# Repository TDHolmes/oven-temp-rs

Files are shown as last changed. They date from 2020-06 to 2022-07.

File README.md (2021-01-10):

# Oven Temperature Monitor

This project utilizes a [Feather M0] board, a [quad alphanumeric display], and a
[thermocouple amplifier] to monitor the temperature of dumb ovens that do
not have digital temperature readout. It is battery opperated, and written
in [rust].

Read more about it [on my website!](https://www.holmesengineering.com/oven-temp-rs/)

# Building and Flashing

As this project uses a [Feather M0] board, it has the [HF2 bootloader] pre-installed from
Adafruit. With the [cargo-hf2] crate installed, building and flashing is as simple as:

1. Place board into bootloader mode (double-press the reset button)
2. Run `cargo hf2 <options>`

To install [cargo-hf2], run `cargo install cargo-hf2`. Additional setup may be needed depending
on your OS. Refer to the crates.io page for more information.

# License

This code is licensed under either of:

- Apache License, Version 2.0 ([LICENSE-APACHE](LICENSE-APACHE) or
  http://www.apache.org/licenses/LICENSE-2.0)
- MIT license ([LICENSE-MIT](LICENSE-MIT) or http://opensource.org/licenses/MIT)

at your option.

## Contribution

Unless you explicitly state otherwise, any contribution intentionally submitted for inclusion in the
work by you, as defined in the Apache-2.0 license, shall be dual licensed as above, without any
additional terms or conditions.

# Schematic / Pictures

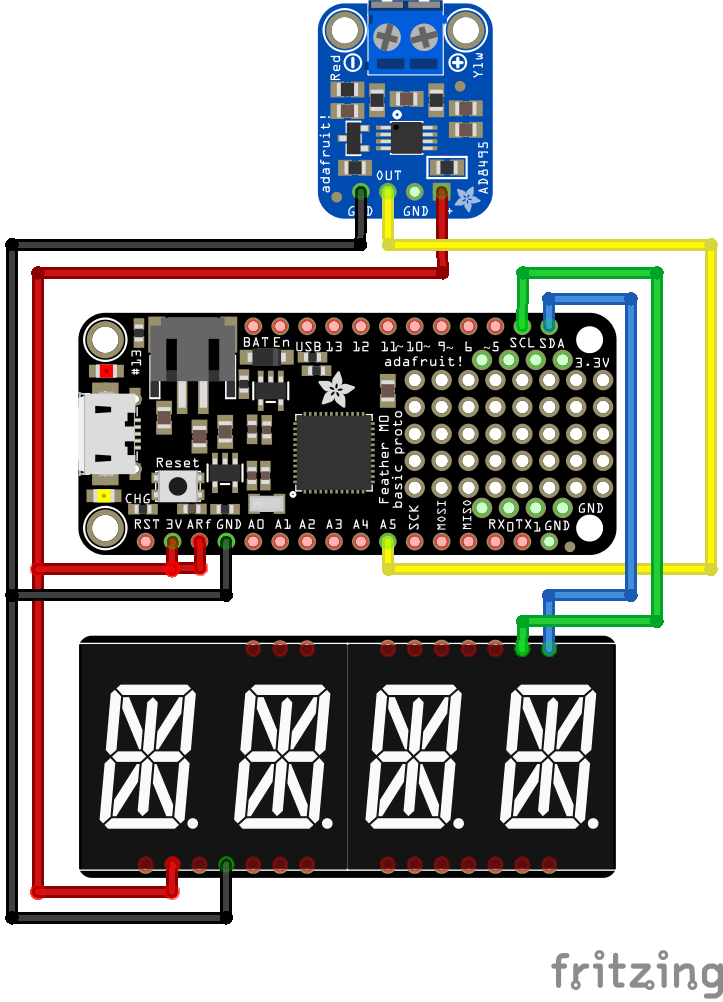
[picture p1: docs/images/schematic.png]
Schematic - very simple


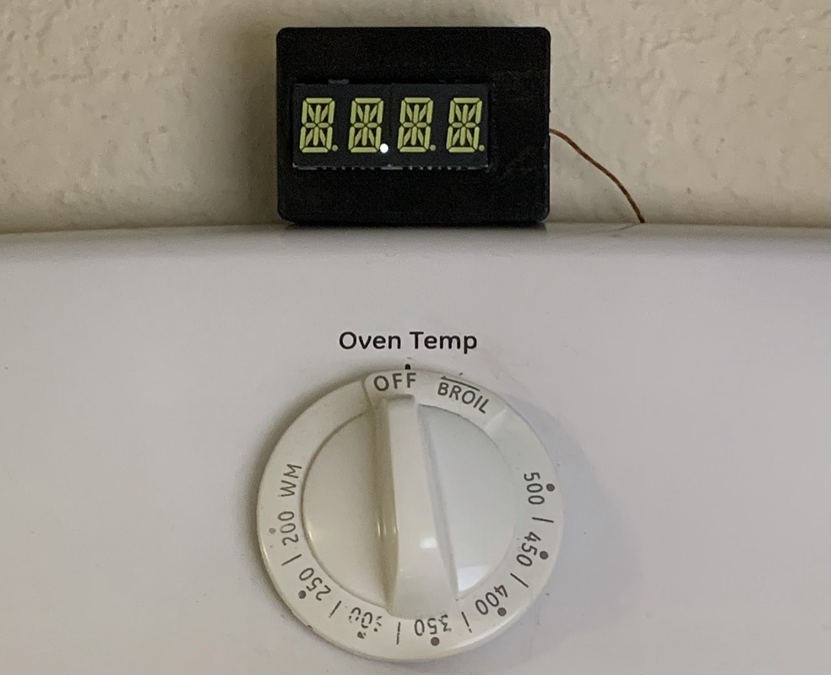
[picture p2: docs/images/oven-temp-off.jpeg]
Picture of the board


[Feather M0]: https://www.adafruit.com/product/2772
[quad alphanumeric display]: https://www.adafruit.com/product/3127
[thermocouple amplifier]: https://www.adafruit.com/product/1778
[rust]: https://rust-lang.org
[oven-temp-board]: https://github.com/TDHolmes/oven-temp-rs/raw/main/docs/images/oven-temp-off.jpeg
[schematic]: https://github.com/TDHolmes/oven-temp-rs/raw/main/docs/images/schematic.png
[HF2 bootloader]: https://github.com/jacobrosenthal/hf2-rs/tree/master/hf2
[cargo-hf2]: https://crates.io/crates/cargo-hf2

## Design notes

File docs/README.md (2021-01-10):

# Rust Oven Temperature Monitor

This project came about when my wife noticed that the oven in our appartment didn't seem to
be at the correct temperature, as everything would bake too quickly. Seeing this as a great
excuse to do a project, I set off on making an oven temperature monitor. To give myself some
constraints, however, I wanted it to be battery powered and last a long time.

My first attempt was written in C using an STM32. you can read more about that [here](https://github.com/TDHolmes/OvenTemp).
This is the new and improved version, written in Rust.



## Hardware Summary

This project utilizes a [Feather M0] board, a [quad alphanumeric display], and a
[thermocouple amplifier] to monitor the temperature of dumb ovens that do
not have digital temperature readout. It is battery opperated, and written
in [rust].

## Initial Implementation

My first cut at this was simple: port all of the basic functionality over from the C-based
version of the project to rust. This was relatively easy given how far along the embedded
rust ecosystem is, especially for these simple projects. Since I'm using a feather M0 board, I used the
wonderful [atsamd-rs] HAL crates. This is a great and welcoming codebase tha also had all of the basic
features I needed to get this project functional. I also took the oportunity to write my own driver for
my alphanumeric display, which I based off of the Adafruit C++ library, with some tweaks for power
I'll get into later on.

## Power Optimizations

I had a functional project up and running quickly, but it definitely wasn't going to work as the
final project. The timer APIs as existed at the time had no capability for interrupt-based
operation, so sleeping the core for power savings wasn't easy. Because of this limitation, I
[opened a PR](https://github.com/atsamd-rs/atsamd/pull/205) for this functionality,
saving 6 mA of current consumption, and I didn't have to worry about interrupt memory saftey since rust didn't
allow me to (easily) do anything unsafe.

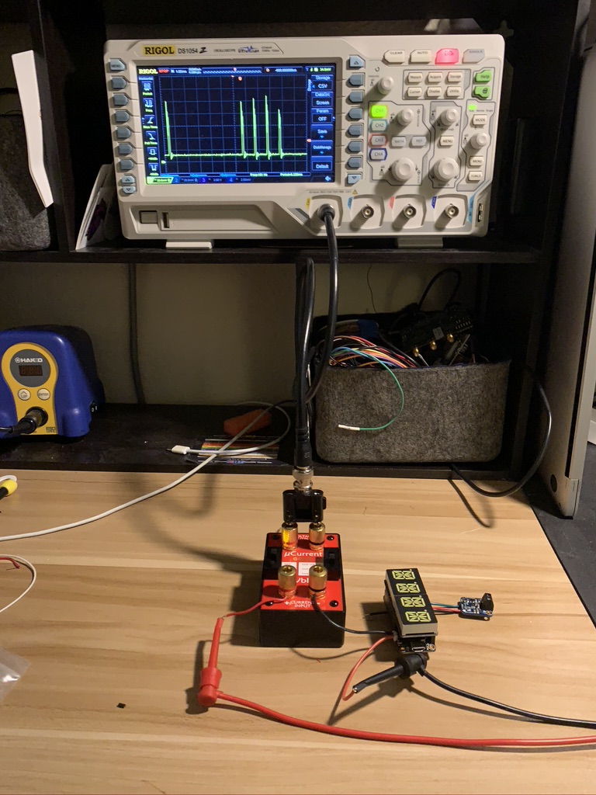
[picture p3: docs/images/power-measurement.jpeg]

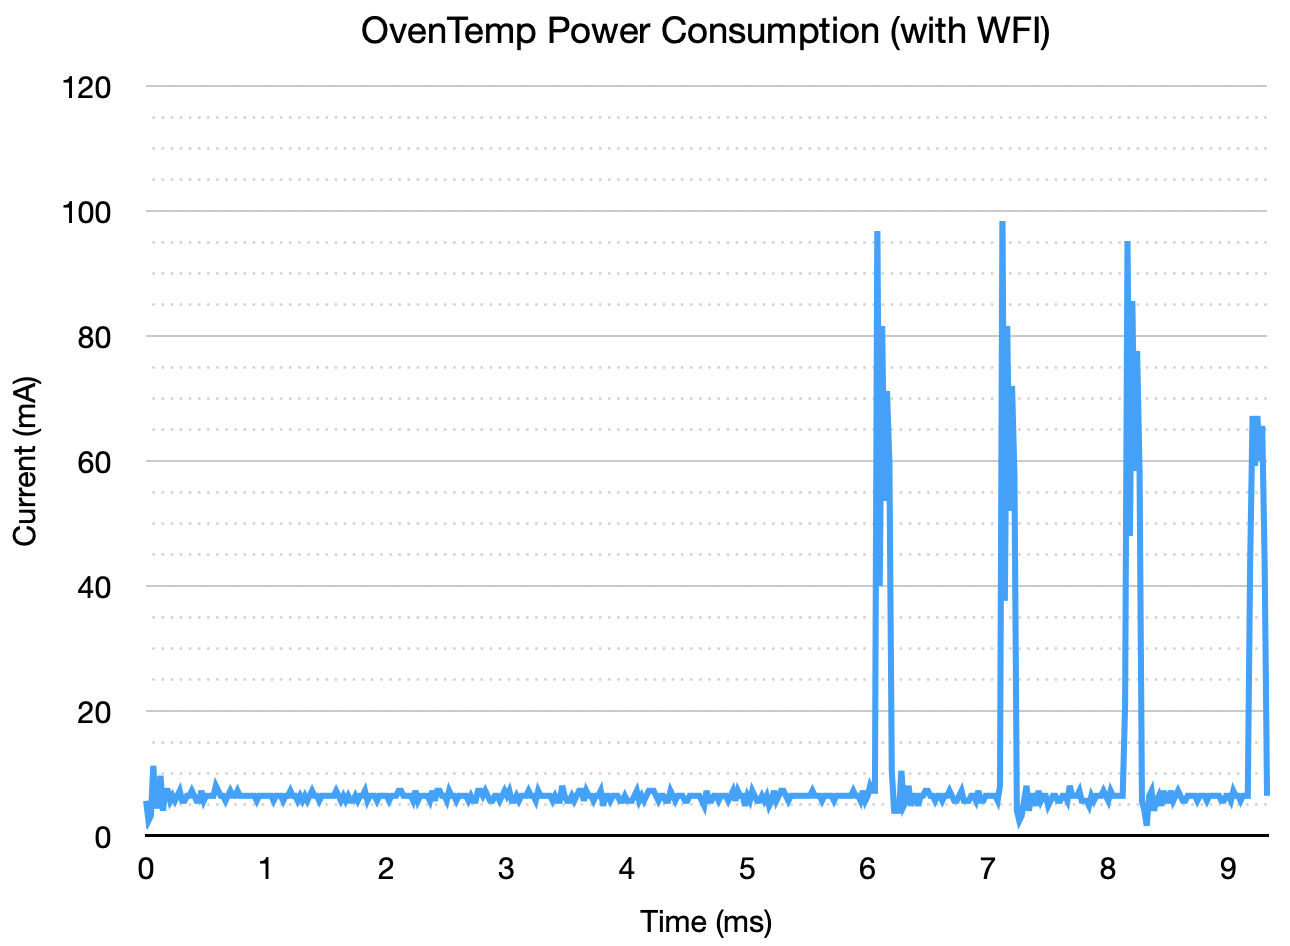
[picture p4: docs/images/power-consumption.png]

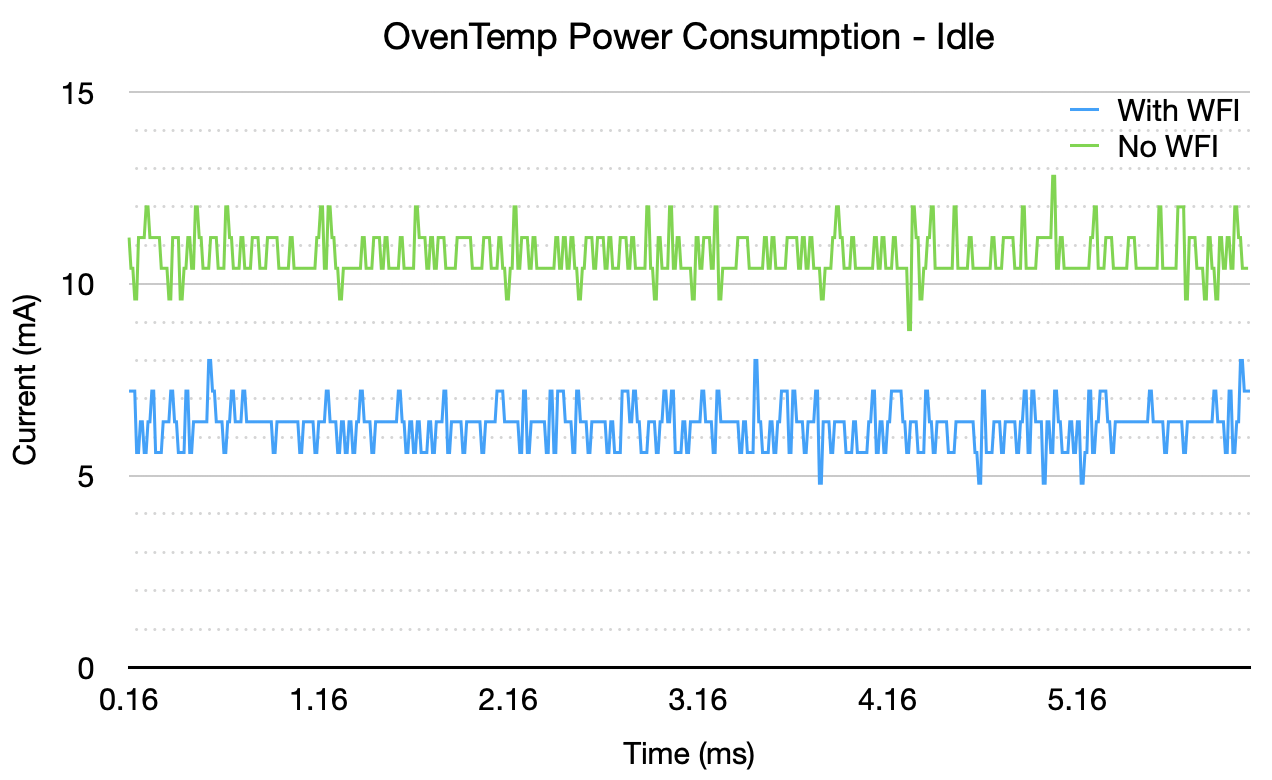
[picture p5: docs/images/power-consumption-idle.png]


This change allowed simple sleeping of the core without powering down much else. A lot more could be
gained by configuring the power management peripheral to sleep more of the cores busses. I implemented
these changes in [this PR](https://github.com/atsamd-rs/atsamd/pull/291), which reduced our current consumption
(apart from the display) from ~870 uA to ~250 uA.

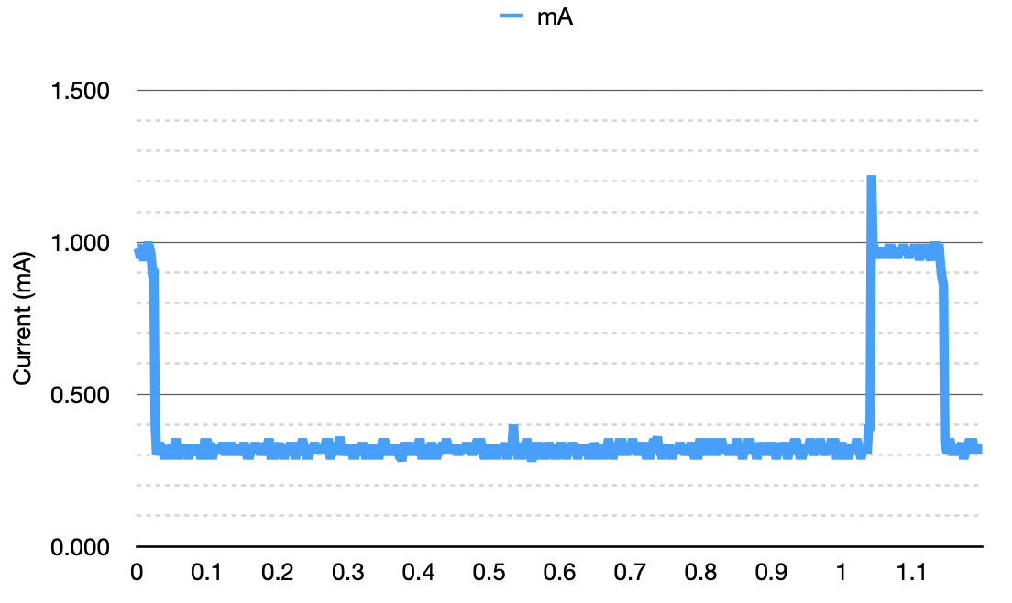
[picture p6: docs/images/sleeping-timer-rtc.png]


This was a large win, however we were still consuming about 5 mA of power in idle. The big delta here came
from the display, which it turns out has an idle mode that isn't exposed in the C++ library I was referencing
when making my rust driver. With the addition of this change, the displays idle current consumption drops
dramatically, bringing us to what I think is the minimum current consumption without making hardware changes,
like a more efficient LDO.

[Feather M0]: https://www.adafruit.com/product/2772
[quad alphanumeric display]: https://www.adafruit.com/product/3127
[thermocouple amplifier]: https://www.adafruit.com/product/1778
[rust]: https://rust-lang.org
[atsamd-rs]: https://github.com/atsamd-rs/atsamd

[oven-temp-board]: https://github.com/TDHolmes/oven-temp-rs/raw/main/docs/images/oven-temp-off.jpeg "The oven temp monitor in place"
[power - wfi]: https://github.com/TDHolmes/oven-temp-rs/raw/main/docs/images/power-consumption-idle.png "Idle power consumption numbers with and without WFI"
[power - overall]: https://github.com/TDHolmes/oven-temp-rs/raw/main/docs/images/power-consumption.png "Measurement of the overall power consumption while displaying a temperature"
[power - measurement]: https://github.com/TDHolmes/oven-temp-rs/raw/main/docs/images/power-measurement.jpeg "Measuring power consumption with the EEVBlog's uCurrent"
[power - standby]: https://github.com/TDHolmes/oven-temp-rs/raw/main/docs/images/sleeping-timer-rtc.png "Power measurements after implementing standby sleeping. The spike is an LED blinking"

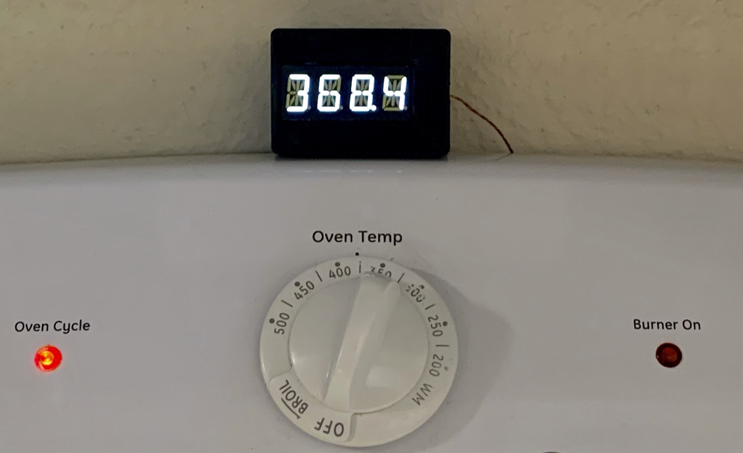
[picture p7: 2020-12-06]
docs/images/oven-temp-on.jpeg

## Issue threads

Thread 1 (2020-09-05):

Improve battery life by using an RTC

TDHolmes, 2020-09-05:
Current battery life isn't horrible, but could definitely be improved by using an RTC-based timer. [atsamd-rs needs an implementation](https://github.com/atsamd-rs/atsamd/issues/44) so would need to complete that first.

TDHolmes, 2020-12-02:
This is done!

Closed 2020-12-02.

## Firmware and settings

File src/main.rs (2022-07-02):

//! Battery powered oven temperature monitor for ovens without digital read-outs.

#![no_std]
#![no_main]
#![warn(rust_2018_idioms)]
#![warn(clippy::all)]

/// 12 bit ADC
const ADC_FULLSCALE: u32 = 4095;
/// Using VDDA / 2 with digital gain 1/2, our reference is ~3.3v
const ADC_REF_VOLTAGE: f32 = 3.3;
/// The threshold for showing a low battery indication.
/// We can't descern much below this voltage due to drop out
const LOW_BATTERY_VOLTAGE: f32 = 3.7;

const DELAY_OFF_MS: u32 = 1_000;
const DELAY_COOLDOWN_MS: u32 = 1_000;
const DELAY_RUNNING_MS: u32 = 1_000;
const SECS_BETWEEN_BLINK: u32 = 5;

use panic_semihosting as _; // Panic handler

#[cfg(feature = "usbserial")]
use oven_temp_rs::serial_write;
#[cfg(feature = "usbserial")]
use oven_temp_rs::usbserial;
use oven_temp_rs::{
    battery, ht16k33,
    oventemp::{OvenTemp, OvenTempState},
};

use bsp::entry;
use bsp::{hal, pac};
use core::sync::atomic;
use cortex_m::peripheral::NVIC;
use feather_m0 as bsp;
use hal::adc::Adc;
use hal::clock::{enable_internal_32kosc, ClockGenId, ClockSource, GenericClockController};
use hal::prelude::*;
use pac::{adc, interrupt, CorePeripherals, Peripherals, TC4};

#[cfg(not(feature = "usbserial"))]
macro_rules! serial_write {
    ($($tt:tt)*) => {{}};
}

/// boolean indicating if our timer interrupt has fired
#[allow(unused)]
static INTERRUPT_FIRED: atomic::AtomicBool = atomic::AtomicBool::new(false);

/// Main function, controlling all of our logic
#[entry]
fn main() -> ! {
    #[allow(unused_mut)] // Only used when usbserial is enabled
    let mut core = CorePeripherals::take().unwrap();
    let mut peripherals = Peripherals::take().unwrap();
    let pins = bsp::Pins::new(peripherals.PORT);

    // just 8 MHz for lower power consumption
    #[cfg(not(feature = "usbserial"))]
    let mut clocks = GenericClockController::with_internal_8mhz(
        peripherals.GCLK,
        &mut peripherals.PM,
        &mut peripherals.SYSCTRL,
        &mut peripherals.NVMCTRL,
    );

    // 48 MHz needed for USB
    #[cfg(feature = "usbserial")]
    let mut clocks = GenericClockController::with_external_32kosc(
        peripherals.GCLK,
        &mut peripherals.PM,
        &mut peripherals.SYSCTRL,
        &mut peripherals.NVMCTRL,
    );

    #[cfg(feature = "usbserial")]
    {
        use oven_temp_rs::usbserial::USBSerial;
        USBSerial::init(
            &mut peripherals.PM,
            peripherals.USB,
            &mut core.NVIC,
            &mut clocks,
            pins.usb_dm,
            pins.usb_dp,
        );
    }

    let mut i2c = bsp::i2c_master(
        &mut clocks,
        400.khz(),
        peripherals.SERCOM3,
        &mut peripherals.PM,
        pins.sda,
        pins.scl,
    );

    let mut red_led = pins.d13.into_push_pull_output();
    red_led.set_high().unwrap();

    #[cfg(feature = "sleeping-delay")]
    let mut runner_delay = {
        use hal::sleeping_delay::SleepingDelay;
        use hal::timer;

        // Get a clock & make a sleeping delay object. use internal 32k clock that runs
        // in standby
        enable_internal_32kosc(&mut peripherals.SYSCTRL);
        let timer_clock = clocks
            .configure_gclk_divider_and_source(ClockGenId::GCLK1, 1, ClockSource::OSC32K, false)
            .unwrap();
        clocks.configure_standby(ClockGenId::GCLK1, true);
        let tc45 = &clocks.tc4_tc5(&timer_clock).unwrap();
        let timer = timer::TimerCounter::tc4_(tc45, peripherals.TC4, &mut peripherals.PM);
        // We can also use it in standby mode, if all of the clocks are configured to
        //   opperate in standby, for even more power savings
        core.SCB.set_sleepdeep();

        unsafe {
            // enable interrupts
            core.NVIC.set_priority(interrupt::TC4, 2);
            NVIC::unmask(interrupt::TC4);
        }

        SleepingDelay::new(timer, &INTERRUPT_FIRED)
    };

    #[cfg(not(feature = "sleeping-delay"))]
    let mut runner_delay = {
        use hal::delay::Delay;

        Delay::new(core.SYST, &mut clocks)
    };

    // wait here until the display is plugged in and communicating
    let mut display = loop {
        match ht16k33::HT16K33::init(0x70, &mut i2c) {
            Ok(disp) => break disp,
            _ => runner_delay.delay_ms(1_000_u32),
        };
    };

    display.clear();
    display.set_brightness(1, &mut i2c).unwrap();
    display.write_str(" HI ");
    display.write_display(&mut i2c).unwrap();
    runner_delay.delay_ms(500_u32);
    display.clear();
    display.write_display(&mut i2c).unwrap();

    let mut adc = Adc::adc(peripherals.ADC, &mut peripherals.PM, &mut clocks);
    adc.gain(adc::inputctrl::GAIN_A::DIV2);
    adc.reference(adc::refctrl::REFSEL_A::INTVCC1);
    adc.samples(adc::avgctrl::SAMPLENUM_A::_32);
    let mut therm_out = pins.a4.into_alternate::<hal::gpio::B>();

    // check the battery voltage (external HW divides the reading by two)
    let mut batt_in_div_2 = pins.d9.into_alternate::<hal::gpio::B>();

    red_led.set_low().unwrap();

    let mut oven_state = OvenTemp::new();
    let mut iteration = 0_u32;

    loop {
        // Check to make sure our battery is in good shape
        let mut battery_reading: f32 = adc.read(&mut batt_in_div_2).unwrap();
        battery_reading =
            2.0 * ((battery_reading as f32 / ADC_FULLSCALE as f32) * ADC_REF_VOLTAGE as f32);

        if battery_reading <= LOW_BATTERY_VOLTAGE {
            // inform user of low battery. Thermocouple readings are not accurate
            display.write_str("LOW");
            display.write_display(&mut i2c).unwrap();
            runner_delay.delay_ms(500_u32);
            display.write_str("BATT");
            display.write_display(&mut i2c).unwrap();
            runner_delay.delay_ms(500_u32);
            display.clear();
            display.write_display(&mut i2c).unwrap();

            // Delay for a long while with display in standby to save some power
            display.configure_standby(&mut i2c, true).unwrap();
            runner_delay.delay_ms(5_000_u32);
            display.configure_standby(&mut i2c, false).unwrap();
            runner_delay.delay_ms(100_u32);
            continue; // Do not run the typical thermocouple routine
        }

        // Check the thermocouple
        let therm_reading: u16 = adc.read(&mut therm_out).unwrap();
        let therm_voltage: f32 =
            (therm_reading as f32 / ADC_FULLSCALE as f32) * ADC_REF_VOLTAGE as f32;
        let temp_c: f32 = (therm_voltage - 1.25) / 0.005;
        let temp: f32 = temp_c * (9. / 5.) + 32.;
        iteration += 1;

        serial_write!("reading: {}.{}\r\n", temp as u32, (temp * 10.) as u32 % 10);

        if run(
            oven_state.state,
            temp,
            &mut i2c,
            &mut display,
            &mut runner_delay,
        )
        .is_err()
        {
            error(&mut red_led, &mut runner_delay);
        }

        if let Some(new_state) = oven_state.check_transition(temp) {
            match new_state {
                OvenTempState::Off | OvenTempState::CoolingDown => {
                    // clear and turn off the display
                    display.clear();
                    if display.write_display(&mut i2c).is_err() {
                        error(&mut red_led, &mut runner_delay);
                    }
                    if display.configure_standby(&mut i2c, true).is_err() {
                        error(&mut red_led, &mut runner_delay);
                    }
                }
                _ => {
                    // take the display out of standby mode
                    if display.configure_standby(&mut i2c, false).is_err() {
                        error(&mut red_led, &mut runner_delay);
                    }
                }
            }
        }

        // blink a dot to show we're alive, and show battery percentage
        let battery_percentage = battery::voltage_to_percentage(battery_reading);
        let mut blink_index: u8 = 0;
        if battery_percentage >= 75 {
            blink_index = 3;
        } else if battery_percentage >= 50 {
            blink_index = 2;
        } else if battery_percentage >= 25 {
            blink_index = 1;
        }

        // blink the dot
        if (oven_state.state == OvenTempState::Off
            || oven_state.state == OvenTempState::CoolingDown)
            && (iteration % SECS_BETWEEN_BLINK == SECS_BETWEEN_BLINK - 1)
        {
            // Turn display on
            if display.configure_standby(&mut i2c, false).is_err() {
                error(&mut red_led, &mut runner_delay);
            }

            // Blink dot
            display.clear();
            display.write_digit_ascii(blink_index, ' ', true);
            if display.write_display(&mut i2c).is_err() {
                error(&mut red_led, &mut runner_delay);
            }
            runner_delay.delay_ms(50_u32);
            display.clear();
            if display.write_display(&mut i2c).is_err() {
                error(&mut red_led, &mut runner_delay);
            }

            // turn display back off
            if display.configure_standby(&mut i2c, false).is_err() {
                error(&mut red_led, &mut runner_delay);
            }
        }
    }
}

/// Display the given temperature on the display
fn display_temp<I2C, CommE>(
    temp_f: f32,
    i2c: &mut I2C,
    display: &mut ht16k33::HT16K33,
) -> Result<(), CommE>
where
    I2C: embedded_hal::blocking::i2c::Write<Error = CommE>,
{
    display.clear();
    if (10. ..100.).contains(&temp_f) {
        let tens_place: u8 = (temp_f / 10.) as u8;
        let ones_place: u8 = (temp_f % 10.) as u8;
        let tenths_place: u8 = ((temp_f * 10.) % 10.) as u8;
        let hundredths_place: u8 = ((temp_f * 100.) % 10.) as u8;
        display.write_digit_value(0, tens_place, false);
        display.write_digit_value(1, ones_place, true);
        display.write_digit_value(2, tenths_place, false);
        display.write_digit_value(3, hundredths_place, false);
    } else if (100. ..600.).contains(&temp_f) {
        let hundreds_place: u8 = (temp_f / 100.) as u8;
        let tens_place: u8 = ((temp_f / 10.) % 10.) as u8;
        let ones_place: u8 = (temp_f % 10.) as u8;
        let tenths_place: u8 = ((temp_f * 10.) % 10.) as u8;
        display.write_digit_value(0, hundreds_place, false);
        display.write_digit_value(1, tens_place, false);
        display.write_digit_value(2, ones_place, true);
        display.write_digit_value(3, tenths_place, false);
    } else {
        // Temp < 10 or >= 600. >= 600 is generally disconnected thermocouple
        display.write_str("ERR!");
    }

    display.write_display(i2c)
}

/// Blinks an SOS pattern indicating an error
///
/// # Parameters
/// * `red_led`: The LED pin to blink
/// * `delay`: The `Delay` instance to wait
fn error<PIN, T>(red_led: &mut PIN, delay: &mut T)
where
    PIN: embedded_hal::digital::v2::OutputPin<Error = core::convert::Infallible>,
    T: embedded_hal::blocking::delay::DelayMs<u32>,
{
    const SHORT_BLIP_MS: u32 = 250;
    const LONG_BLIP_MS: u32 = 500;

    // S
    red_led.set_high().unwrap();
    delay.delay_ms(SHORT_BLIP_MS);
    red_led.set_low().unwrap();
    delay.delay_ms(SHORT_BLIP_MS);
    red_led.set_high().unwrap();
    delay.delay_ms(SHORT_BLIP_MS);
    red_led.set_low().unwrap();
    delay.delay_ms(SHORT_BLIP_MS);
    red_led.set_high().unwrap();
    delay.delay_ms(SHORT_BLIP_MS);
    red_led.set_low().unwrap();
    delay.delay_ms(SHORT_BLIP_MS);

    // O
    red_led.set_high().unwrap();
    delay.delay_ms(LONG_BLIP_MS);
    red_led.set_low().unwrap();
    delay.delay_ms(LONG_BLIP_MS);
    red_led.set_high().unwrap();
    delay.delay_ms(LONG_BLIP_MS);
    red_led.set_low().unwrap();
    delay.delay_ms(LONG_BLIP_MS);
    red_led.set_high().unwrap();
    delay.delay_ms(LONG_BLIP_MS);
    red_led.set_low().unwrap();
    delay.delay_ms(LONG_BLIP_MS);

    // S
    red_led.set_high().unwrap();
    delay.delay_ms(SHORT_BLIP_MS);
    red_led.set_low().unwrap();
    delay.delay_ms(SHORT_BLIP_MS);
    red_led.set_high().unwrap();
    delay.delay_ms(SHORT_BLIP_MS);
    red_led.set_low().unwrap();
    delay.delay_ms(SHORT_BLIP_MS);
    red_led.set_high().unwrap();
    delay.delay_ms(SHORT_BLIP_MS);
    red_led.set_low().unwrap();

    delay.delay_ms(2 * LONG_BLIP_MS);
}

/// Run the main state display/sleep logic
pub fn run<I2C, CommError, T>(
    state: OvenTempState,
    temp: f32,
    i2c: &mut I2C,
    display: &mut ht16k33::HT16K33,
    delay: &mut T,
) -> Result<(), CommError>
where
    I2C: embedded_hal::blocking::i2c::Write<Error = CommError>,
    T: embedded_hal::blocking::delay::DelayMs<u32>,
{
    match state {
        OvenTempState::Off => {
            serial_write!("Off\r\n");
            delay.delay_ms(DELAY_OFF_MS);
            Ok(())
        }
        OvenTempState::CoolingDown => {
            serial_write!("CoolingDown\r\n");
            delay.delay_ms(DELAY_COOLDOWN_MS);
            Ok(())
        }
        _ => {
            serial_write!("WarmingUp or AtTemp\r\n");
            let ret = display_temp(temp, i2c, display);
            delay.delay_ms(DELAY_RUNNING_MS);
            ret
        }
    }
}

/// The sleeping timer interrupt that wakes us up
#[interrupt]
fn TC4() {
    // Let the sleepingtimer know that the interrupt fired, and clear it
    INTERRUPT_FIRED.store(true, atomic::Ordering::Relaxed);
    unsafe {
        TC4::ptr()
            .as_ref()
            .unwrap()
            .count16()
            .intflag
            .modify(|_, w| w.ovf().set_bit());
    }
}

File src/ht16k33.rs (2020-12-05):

//! HT16K33 segment display driver, based on the Adafruit Arduino driver.

const DISPLAY_BUFFER_SIZE: usize = 8;

const ALPHA_FONT_TABLE: [u16; 128] = [
    0b0000_0000_0000_0001,
    0b0000_0000_0000_0010,
    0b0000_0000_0000_0100,
    0b0000_0000_0000_1000,
    0b0000_0000_0001_0000,
    0b0000_0000_0010_0000,
    0b0000_0000_0100_0000,
    0b0000_0000_1000_0000,
    0b0000_0001_0000_0000,
    0b0000_0010_0000_0000,
    0b0000_0100_0000_0000,
    0b0000_1000_0000_0000,
    0b0001_0000_0000_0000,
    0b0010_0000_0000_0000,
    0b0100_0000_0000_0000,
    0b1000_0000_0000_0000,
    0b0000_0000_0000_0000,
    0b0000_0000_0000_0000,
    0b0000_0000_0000_0000,
    0b0000_0000_0000_0000,
    0b0000_0000_0000_0000,
    0b0000_0000_0000_0000,
    0b0000_0000_0000_0000,
    0b0000_0000_0000_0000,
    0b0001_0010_1100_1001,
    0b0001_0101_1100_0000,
    0b0001_0010_1111_1001,
    0b0000_0000_1110_0011,
    0b0000_0101_0011_0000,
    0b0001_0010_1100_1000,
    0b0011_1010_0000_0000,
    0b0001_0111_0000_0000,
    0b0000_0000_0000_0000, //
    0b0000_0000_0000_0110, // !
    0b0000_0010_0010_0000, // "
    0b0001_0010_1100_1110, // #
    0b0001_0010_1110_1101, // $
    0b0000_1100_0010_0100, // %
    0b0010_0011_0101_1101, // &
    0b0000_0100_0000_0000, // '
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
];

// const DISP_I2C_ADDR: u8 = (0x70 << 1);

// const LED_ON: u8 = 1;
// const LED_OFF: u8 = 0;

// const LED_RED: u8 = 1;
// const LED_YELLOW: u8 = 2;
// const LED_GREEN: u8 = 3;

const HT16K33_BLINK_CMD: u8 = 0x80;
const HT16K33_BLINK_DISPLAYON: u8 = 0x01;
const HT16K33_BLINK_OFF: u8 = 0;
// const HT16K33_BLINK_2HZ: u8 = 1;
// const HT16K33_BLINK_1HZ: u8 = 2;
// const HT16K33_BLINK_HALFHZ: u8 = 3;

const HT16K33_SYSTEM_SETUP: u8 = 0x20;
const HT16K33_SYSTEM_SETUP_NORMAL: u8 = 0x01;
const HT16K33_SYSTEM_SETUP_STANDBY: u8 = 0x00;
const HT16K33_CMD_BRIGHTNESS: u8 = 0xE0;
// const SEVENSEG_DIGITS: u8 = 5;

// const DEC: u8 = 10;
// const HEX: u8 = 16;
// const OCT: u8 = 8;
// const BIN: u8 = 2;
// const BYTE: u8 = 0;

const ALPHA_POINT_MASK: u16 = 1 << 14;

pub struct HT16K33 {
    i2c_addr: u8,
    display_buffer: [u16; DISPLAY_BUFFER_SIZE],
}

impl HT16K33 {
    pub fn init<I2C, CommE>(addr: u8, i2c: &mut I2C) -> Result<Self, CommE>
    where
        I2C: embedded_hal::blocking::i2c::Write<Error = CommE>,
    {
        let mut ht = Self {
            i2c_addr: addr,
            display_buffer: [0; DISPLAY_BUFFER_SIZE],
        };

        // turn on oscillator
        ht.configure_standby(i2c, false)?;
        ht.blink_rate(HT16K33_BLINK_OFF, i2c)?;
        ht.set_brightness(15, i2c)?; // max brightness

        Ok(ht)
    }

    pub fn set_brightness<I2C, CommE>(&mut self, b: u8, i2c: &mut I2C) -> Result<(), CommE>
    where
        I2C: embedded_hal::blocking::i2c::Write<Error = CommE>,
    {
        let mut b = b;
        if b > 15 {
            b = 15;
        }
        let data: [u8; 1] = [HT16K33_CMD_BRIGHTNESS | b];
        i2c.write(self.i2c_addr, &data)?;
        Ok(())
    }

    pub fn blink_rate<I2C, CommE>(&mut self, b: u8, i2c: &mut I2C) -> Result<(), CommE>
    where
        I2C: embedded_hal::blocking::i2c::Write<Error = CommE>,
    {
        let mut bm = b;
        if bm > 3 {
            bm = 0; // turn off if not sure
        }

        let data: [u8; 1] = [HT16K33_BLINK_CMD | HT16K33_BLINK_DISPLAYON | (bm << 1)];
        i2c.write(self.i2c_addr, &data)?;
        Ok(())
    }

    pub fn configure_standby<I2C, CommE>(
        &mut self,
        i2c: &mut I2C,
        standby: bool,
    ) -> Result<(), CommE>
    where
        I2C: embedded_hal::blocking::i2c::Write<Error = CommE>,
    {
        if standby {
            i2c.write(
                self.i2c_addr,
                &[HT16K33_SYSTEM_SETUP | HT16K33_SYSTEM_SETUP_STANDBY],
            )?;
        } else {
            i2c.write(
                self.i2c_addr,
                &[HT16K33_SYSTEM_SETUP | HT16K33_SYSTEM_SETUP_NORMAL],
            )?;
        }

        Ok(())
    }

    pub fn clear(&mut self) {
        for i in 0..8 {
            self.display_buffer[i] = 0;
        }
    }

    pub fn write_digit_value(&mut self, n: u8, number: u8, point: bool) {
        self.display_buffer[n as usize] = ALPHA_FONT_TABLE[(number + 0x30) as usize];
        if point {
            self.display_buffer[n as usize] |= ALPHA_POINT_MASK;
        }
    }

    pub fn write_str(&mut self, msg: &str) {
        for (index, c) in msg.chars().enumerate() {
            self.write_digit_ascii(index as u8, c, false);
            if index >= 4 {
                break;
            }
        }
    }

    pub fn write_digit_ascii(&mut self, n: u8, character: char, point: bool) {
        self.display_buffer[n as usize] = ALPHA_FONT_TABLE[character as usize];
        if point {
            self.display_buffer[n as usize] |= ALPHA_POINT_MASK;
        }
    }

    pub fn write_display<I2C, CommE>(&mut self, i2c: &mut I2C) -> Result<(), CommE>
    where
        I2C: embedded_hal::blocking::i2c::Write<Error = CommE>,
    {
        // Build up the payload. Start with 0
        let mut data: [u8; 17] = [0; 17];
        data[0] = 0;
        for i in 0..8 {
            data[2 * i + 1] = (self.display_buffer[i as usize] & 0xFF) as u8;
            data[2 * i + 2] = (self.display_buffer[i as usize] >> 8) as u8;
        }
        i2c.write(self.i2c_addr, &data)?;
        Ok(())
    }
}

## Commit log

2020-05-27 fixup usbserial operation & utilize feature flags to compile it out
    [main.rs, usbserial.rs]
2020-06-05 add some pictures
    [schematic.fzz]
2020-06-05 error should loop forever
    [main.rs]
2020-06-07 error method is now captive
    [main.rs]
2020-06-07 IDLE2 for better power consumption in sleep
2020-06-09 INTERRUPT_FIRED global does not need to be mutable
2020-06-09 lowest display brightness for power savings
2020-06-11 add low battery indication
2020-06-11 fix delay being moved when not using sleeping delay
    [main.rs]
2020-11-27 various fixes
    - Fix USB serial feature
    - update cortex-m library a little
    - fix heartbeat blink
    - 32x samples for the ADC to have more accurate temp & battery measurement
    [main.rs, usbserial.rs]
2020-11-28 make error function just blink SOS once so we can hopefully recover from transient errors
    [main.rs]
2020-12-05 fix error blink leaving red LED on
    [main.rs]
2020-12-05 add battery estimation & show that to the user
2021-01-10 switch CI to main
